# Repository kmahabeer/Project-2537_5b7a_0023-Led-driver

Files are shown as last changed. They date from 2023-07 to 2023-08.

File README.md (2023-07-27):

# LED Driver Circuit

Welcome to my photogrammetry project! Within this repository, you will find the KiCad PCB design, as well as the firmware for the LED driver circuit. The LED driver circuit is a crucial component in my photogrammetry project.

## Introduction

My photogrammetry project focuses on creating photorealistic digital clones using a low-budget image capture system with precise illumination facilitated by several LED driver circuits. Precise, multispectral lighting is important for accurate image capture. The images captured are used to recreate texture maps, including diffuse, specular, and roughness maps. Additionally, the images captured serve as valuable training data for creating deepfake models.

The LED driver circuit consists of constant current drivers powering five LEDs, including RGB LEDs, a PC Amber LED, and a neutral white LED. Each circuit incorporates a cost-effective 8-bit Microchip PIC16 microcontroller. Ethernet communication between a main computer through a Power over Ethernet (PoE) switch will be used<sup><a href="#item1">[1]</a></sup>. The microcontroller will most likely implement a lightweight TCP/IP stack where a main computer sends either UDP or TCP packets. While a UDP or TCP packet can be sent via simple commands from the main computer, a custom application will be developed to automate this process once several LED driver circuits are implemented.

Please note that the resources herein are intended solely for this specific project and should not be used elsewhere. My intent for creating the photogrammetry project is my own personal use, and is not intended to create digital clones of anyone besides myself.

## Components

Some important components included in the schematic:

- Microchip PIC16F18026
- Microchip PD70210
- Cree LED JE2835 3V N-Class LEDs
- Luxeon 2835E Neutral White LEDs

## Directory Structure

- `LED-driver-kicad/`: KiCad schematic files (.sch), KiCad PCB layout files (.kicad_pcb) for the main circuit.
- `firmware/`: Any firmware-related code for the microcontroller.
- `Documentation/`: Any relevant documentation or datasheets used in the design.

## References

<ol>
<li id="item1">
“IEEE Standard for Information technology-- Local and metropolitan area networks-- Specific requirements-- Part 3: CSMA/CD Access Method and Physical Layer Specifications Amendment 3: Data Terminal Equipment (DTE) Power via the Media Dependent Interface (MDI) Enhancements” <i>IEEE Standards Association</i>, 30 Oct. 2009, <a href="https://standards.ieee.org/ieee/802.3at/4553/" target="_blank" rel="noopener noreferrer">standards.ieee.org/ieee/802.3at/4553/</a>.
</li>
</ol>

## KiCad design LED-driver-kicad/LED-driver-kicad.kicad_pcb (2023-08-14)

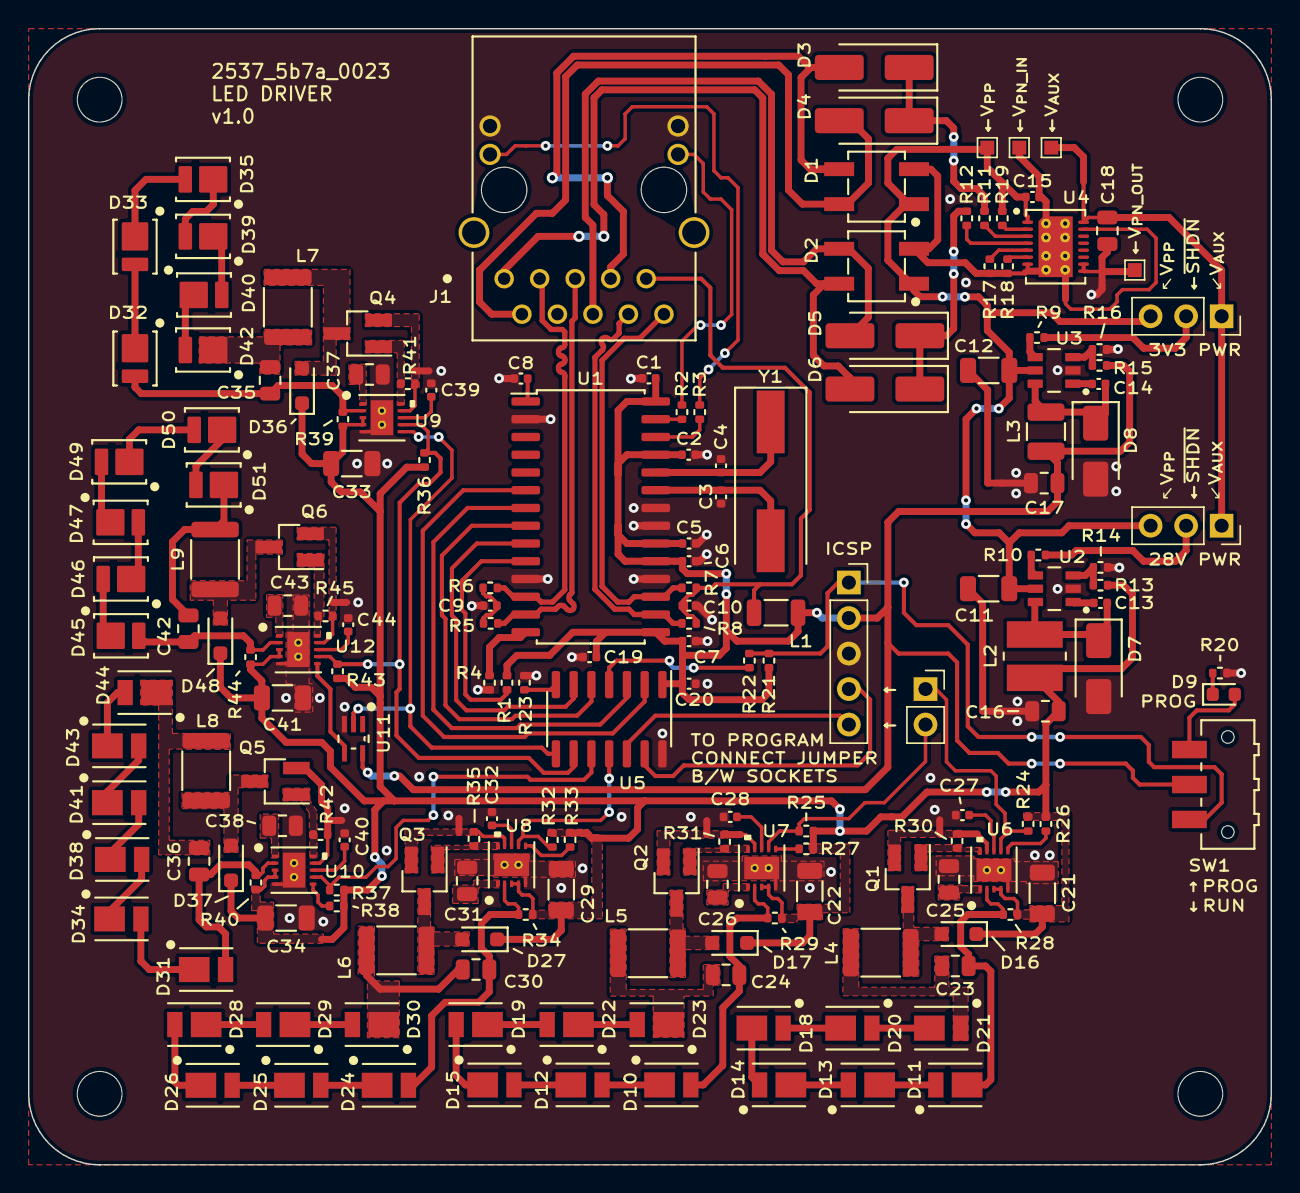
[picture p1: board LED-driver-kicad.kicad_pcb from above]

Board: 2 copper layers, 88.9 x 81.3 mm, 192 parts (0 on the bottom side), 140 nets.

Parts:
C1, C2, C5, C6, C7, C9, C10, C13, C14, C15, C20: 100n; C_0402_1005Metric
C3, C4: 18p; C_0402_1005Metric
C8: 10u; C_0402_1005Metric
C11, C12: 2u2; C_1206_3216Metric
C16, C18, C23, C24, C25, C26, C30, C31, C35, C36, C37, C38, C42, C43: 4u7; C_0805_2012Metric
C17: 22u; C_0805_2012Metric
C19: 10n; C_0402_1005Metric
C21, C22, C29, C33, C34, C41: 10u; C_1206_3216Metric
C27, C28, C32, C39, C40, C44: 470p; C_0402_1005Metric
D1, D2: D_Bridge_+A-A; D_TO-269AA_4-BESOP_Diodes_MB10S-13
D3, D4, D5, D6: D; D_SMA_Handsoldering
D7, D8: SMC SS110; D_SMA
D9: GREEN; LED_0603_1608Metric
D10, D12, D15, D19, D22, D23: GREEN; LED_Cree-JE2835_3V_NClass_Group-1
D11, D13, D14, D18, D20, D21: RED; LED_Cree-JE2835_3V_NClass_Group-2
D16, D17, D27, D36, D37, D48: SD103AWS; D_SOD-323_HandSoldering
D24, D25, D26, D28, D29, D30: BLUE; LED_Cree-JE2835_3V_NClass_Group-1
D31, D34, D38, D41, D43, D44: PCAmber; LED_Cree-JE2835_3V_NClass_Group-1
D32, D33, D35, D39, D40, D42, D45, D46, D47, D49, D50, D51: White; LED_Lumiled_Luxeon_2835E_3V
H1, H2, H3, H4: MountingHole; MountingHole_3.2mm_M3
J1: ARJM11C7-114-BA-EW2; Connector_RJ45_Abracon_ARJM11C7-114-BA-EW2
J2, J3: Conn_01x03_Socket; PinSocket_1x03_P2.54mm_Vertical
J4: Conn_01x05_Socket; PinSocket_1x05_P2.54mm_Vertical
J5: Conn_01x02_Socket; PinSocket_1x02_P2.54mm_Vertical
L1: Ferrite Bead; L_1206_3216Metric
L2: 100u; L_TDK_VLS4015CX-6R8M-H
L3: 22u; L_1210_3225Metric
L4, L5, L6, L7, L8, L9: 330u; L_1812_4532Metric
NT1, NT2, NT3, NT4, NT5, NT6, NT7, NT8, NT9, NT10: NetTie_2; NetTie-2_SMD_Pad0.5mm
Q1, Q2, Q3, Q4, Q5, Q6: Q_NMOS_GDS; SOT-23_Handsoldering
R1, R11, R12, R14, R16, R21, R30, R31, R35, R41, R42, R45: 10k; R_0402_1005Metric
R2, R3: 1k; R_0402_1005Metric
R4: 2k32; R_0402_1005Metric
R5, R6, R7, R8: 49R9; R_0402_1005Metric
R9, R10, R24, R25, R26, R27, R32, R33, R36, R37, R38, R43: 100k; R_0402_1005Metric
R13: 357k; R_0402_1005Metric
R15: 33k; R_0402_1005Metric
R17: 60k4; R_0402_1005Metric
R18: 30R9; R_0402_1005Metric
R19: 25k; R_0402_1005Metric
R20: 100; R_0402_1005Metric
R22, R23: 470; R_0402_1005Metric
R28, R29, R34, R39, R40, R44: 1.43; R_0402_1005Metric
SW1: SW_SPDT; SW_SPDT_CK-JS102011SAQN
TP1, TP2, TP3, TP4: TestPoint; TestPoint_Pad_1.0x1.0mm
U1: ENC28J60x-SO; SOIC-28W_7.5x17.9mm_P1.27mm
U2, U3: LV2862XLVDDCR; SOT-23-Thin-6_DDC0006A-MFG_Regulator_Voltage_TI_LV2862XLVDD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
U4: PD70210A; DFN-16_5X4_MCH-Interface_PoE_Microchip_PD70210A
U5: PIC16F18026-ISL; SOIC-14_3.9x8.7mm_P1.27mm
U6, U7, U8, U9, U10, U12: MIC3205YML-TR; MLF-10_ML_MCH-Driver_LED_Microchip_MIC3205YML-TR
U11: 74AHC1G14; SOT-353-DCK5-Logic_Diodes_74AHC1G14SE-7
Y1: 25MHz; Crystal_SMD_HC49-SD

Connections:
+3.3V: C1.1, C2.1, C5.1, C6.1, C7.1, C17.1, C19.1, C20.1, J4.2, L1.1, L3.2, R1.2, R15.1, R21.1, SW1.2 (B), U1.15 (VDDTX), U1.19 (VDDRX), U1.20 (VDDPLL), U1.25 (VDDOSC), U1.28 (VDD), U5.1 (VDD), U11.5 (VCC)
+28V: C16.1, C21.1, C22.1, C29.1, C33.1, C34.1, C41.1, D16.1 (K), D17.1 (K), D27.1 (K), D36.1 (K), D37.1 (K), D48.1 (K), L2.2, R13.1, R24.1, R25.1, R26.1, R27.1, R28.1, R29.1, R32.1, R33.1, R34.1, R36.1, R37.1, R38.1, R39.1, R40.1, R43.1, R44.1, U6.3 (VIN), U6.4 (VINS), U7.3 (VIN), U7.4 (VINS), U8.3 (VIN), U8.4 (VINS), U9.3 (VIN), U9.4 (VINS), U10.3 (VIN), U10.4 (VINS), U12.3 (VIN), U12.4 (VINS)
/Ethernet/RJ45_LED_L_ANODE: J1.13 (LED), R2.2
/Ethernet/RJ45_LED_R_ANODE: J1.11 (LED), R3.2
/Ethernet/RJ45_RD+: J1.5 (RD+), R5.1, U1.13 (TPIN+)
/Ethernet/RJ45_RD-: J1.3 (RD-), R6.1, U1.12 (TPIN-)
/Ethernet/RJ45_TCT: C10.1, J1.9 (TCT), L1.2, R7.2, R8.1
/Ethernet/RJ45_TD+: J1.10 (TD+), R7.1, U1.17 (TPOUT+)
/Ethernet/RJ45_TD-: J1.8 (TD-), R8.2, U1.16 (TPOUT-)
/LEDs - amber and white/PGND_AMBER: NT8.2, Q5.3 (S), R42.2, U10.9 (PGND)
/LEDs - amber and white/PGND_WHITE: NT9.1, Q4.3 (S), R41.2, U9.9 (PGND)
/LEDs - amber and white/PGND_WHITE_P: NT10.1, Q6.3 (S), R45.2, U12.9 (PGND)
/LEDs/PGND_BLUE: NT7.2, Q3.3 (S), R35.2, U8.9 (PGND)
/LEDs/PGND_GREEN: NT5.2, Q2.3 (S), R31.2, U7.9 (PGND)
/LEDs/PGND_RED: NT6.2, Q1.3 (S), R30.2, U6.9 (PGND)
/Microcontroller/MCU_ICSP_MCLR: J4.1, R21.2, R22.1, SW1.1 (A)
/Power/3V3_C_{IN}_GND: C12.2, NT2.1
/Power/3V3_~SHDN: J2.2, R9.2
/Power/28V_C_{IN}_GND: C11.2, NT1.1
/Power/28V_~SHDN: J3.2, R10.2
/Power/VAUX: C18.1, J2.1, J3.1, TP3.1, U4.16 (VAUX)
/Power/VPN_IN: C15.2, D1.3 (-), D2.3 (-), NT3.1, R17.2, R18.2, TP2.1, U4.7 (VPN_IN), U4.8 (VPN_IN), U4.17 (ePAD)
/Power/VPN_OUT: C18.2, NT4.2, TP4.1, U4.9 (VPN_OUT), U4.10 (VPN_OUT)
/Power/VPP: C11.1, C12.1, C15.1, D1.1 (+), D2.1 (+), J2.3, J3.3, R19.1, TP1.1, U2.5 (VIN), U3.5 (VIN), U4.1 (VPP)
/Power/WA_EN: NT3.2, U4.15 (WA_EN)
GND: C1.2, C2.2, C3.1, C4.1, C5.2, C6.2, C7.2, C8.2, C9.2, C10.2, C16.2, C17.2, C19.2, C20.2, C21.2, C22.2, C25.2, C26.2, C27.2, C28.2, C29.2, C31.2, C32.2, C33.2, C34.2, C37.2, C38.2, C39.2, C40.2, C41.2, C43.2, C44.2, D7.2 (A), D8.2 (A), J1.12 (LED), J1.14 (LED), J4.3, NT1.2, NT2.2, NT4.1, NT5.1, NT6.1, NT7.1, NT8.1, NT9.2, NT10.2, R4.1, R14.2, R16.2, R20.1, R23.1, U1.2 (VSS), U1.11 (VSSRX), U1.18 (VSSTX), U1.21 (VSSPLL), U1.22 (VSSOSC), U2.2 (GND), U3.2 (GND), U5.14 (VSS), U6.5 (AGND), U6.11 (ePAD), U7.5 (AGND), U7.11 (ePAD), U8.5 (AGND), U8.11 (ePAD), U9.5 (AGND), U9.11 (ePAD), U10.5 (AGND), U10.11 (ePAD), U11.3 (GND), U12.5 (AGND), U12.11 (ePAD)
MCU_CCP1: R36.2, R43.2, U5.9 (RC1), U9.7 (DIM), U12.7 (DIM)
MCU_CCP2: R37.2, U5.10 (RC0), U10.7 (DIM)
MCU_PWM3_OUT: R32.2, U5.11 (RA2), U8.7 (DIM)
MCU_PWM4_OUT: J5.2, R25.2, U7.7 (DIM)
MCU_PWM5_OUT: J5.1, R24.2, U6.7 (DIM)
MCU_SPI_ETH_CS: U1.9 (~CS), U5.6 (RC4)
MCU_SPI_SCK: U1.8 (SCK), U5.5 (RC5)
MCU_SPI_SDI/MOSI: U1.6 (SO), U5.2 (RA5)
MCU_SPI_SDO/MISO: U1.7 (SI), U5.3 (RA4)
MCU_WHITE_LED: U5.8 (RC2), U9.6 (EN), U11.2
unnamed: C9.1, R5.2, R6.2
unnamed: D3.1 (K), D4.1 (K), R11.2
unnamed: D5.1 (K), D6.1 (K), R12.1
unnamed: C13.2, D7.1 (K), L2.1, U2.6 (SW)
unnamed: C14.2, D8.1 (K), L3.1, U3.6 (SW)
unnamed: D9.2 (A), SW1.3 (C)
unnamed: D9.1 (K), R20.2
unnamed: C24.1, D10.2 (A), R29.2, U7.2 (CS)
unnamed: D10.1 (K), D12.2 (A)
unnamed: C23.1, D11.2 (A), R28.2, U6.2 (CS)
unnamed: D11.1 (K), D13.2 (A)
unnamed: D12.1 (K), D15.2 (A)
unnamed: D13.1 (K), D14.2 (A)
unnamed: D14.1 (K), D18.2 (A)
unnamed: D15.1 (K), D19.2 (A)
unnamed: D16.2 (A), L4.2, Q1.2 (D)
unnamed: D17.2 (A), L5.2, Q2.2 (D)
unnamed: D18.1 (K), D20.2 (A)
unnamed: D19.1 (K), D22.2 (A)
unnamed: D20.1 (K), D21.2 (A)
unnamed: C23.2, D21.1 (K), L4.1
unnamed: D22.1 (K), D23.2 (A)
unnamed: C24.2, D23.1 (K), L5.1
unnamed: C30.1, D24.2 (A), R34.2, U8.2 (CS)
unnamed: D24.1 (K), D25.2 (A)
unnamed: D25.1 (K), D26.2 (A)
unnamed: D26.1 (K), D28.2 (A)
unnamed: D27.2 (A), L6.2, Q3.2 (D)
unnamed: D28.1 (K), D29.2 (A)
unnamed: D29.1 (K), D30.2 (A)
unnamed: C30.2, D30.1 (K), L6.1
unnamed: C36.1, D31.2 (A), R40.2, U10.2 (CS)
unnamed: D31.1 (K), D34.2 (A)
unnamed: C35.1, D32.2 (A), R39.2, U9.2 (CS)
unnamed: D32.1 (K), D33.2 (A)
unnamed: D33.1 (K), D35.2 (A)
unnamed: D34.1 (K), D38.2 (A)
unnamed: D35.1 (K), D39.2 (A)
unnamed: D36.2 (A), L7.2, Q4.2 (D)
unnamed: D37.2 (A), L8.2, Q5.2 (D)
unnamed: D38.1 (K), D41.2 (A)
unnamed: D39.1 (K), D40.2 (A)
unnamed: D40.1 (K), D42.2 (A)
unnamed: D41.1 (K), D43.2 (A)
unnamed: C35.2, D42.1 (K), L7.1
unnamed: D43.1 (K), D44.2 (A)
unnamed: C36.2, D44.1 (K), L8.1
unnamed: C42.1, D45.2 (A), R44.2, U12.2 (CS)
unnamed: D45.1 (K), D46.2 (A)
unnamed: D46.1 (K), D47.2 (A)
unnamed: D47.1 (K), D49.2 (A)
unnamed: D48.2 (A), L9.2, Q6.2 (D)
unnamed: D49.1 (K), D50.2 (A)
unnamed: D50.1 (K), D51.2 (A)
unnamed: C42.2, D51.1 (K), L9.1
unnamed: J4.4, U5.13 (RA0/ICSPDAT)
unnamed: J4.5, U5.12 (RA1/ICSPCLK)
unnamed: Q1.1 (G), R30.1, U6.10 (DRV)
unnamed: Q2.1 (G), R31.1, U7.10 (DRV)
unnamed: Q3.1 (G), R35.1, U8.10 (DRV)
unnamed: Q4.1 (G), R41.1, U9.10 (DRV)
unnamed: Q5.1 (G), R42.1, U10.10 (DRV)
unnamed: Q6.1 (G), R45.1, U12.10 (DRV)
unnamed: R2.1, U1.27 (LEDA)
unnamed: R3.1, U1.26 (LEDB)
unnamed: C3.2, U1.23 (OSC1), Y1.2
unnamed: C4.2, U1.24 (OSC2), Y1.1
unnamed: R4.2, U1.14 (RBIAS)
unnamed: C8.1, U1.1 (VCAP)
unnamed: R1.1, U1.10 (~RESET)
unnamed: C13.1, U2.1 (CB)
unnamed: R13.2, R14.1, U2.3 (FB)
unnamed: R10.1, U2.4 (~SHDN)
unnamed: C14.1, U3.1 (CB)
unnamed: R15.2, R16.1, U3.3 (FB)
unnamed: R9.1, U3.4 (~SHDN)
unnamed: R18.1, U4.6 (RCLS)
unnamed: R19.2, U4.2 (RDET)
unnamed: R17.1, U4.5 (RREF)
unnamed: R11.1, U4.3 (SUPP_S1)
unnamed: R12.2, U4.4 (SUPP_S2)
unnamed: R23.2, U5.7 (RC3)
unnamed: R22.2, U5.4 (~MCLR/Vpp/RA3)
unnamed: C27.1, U6.8 (CTIMER)
unnamed: R26.2, U6.6 (EN)
unnamed: C25.1, U6.1 (VCC)
unnamed: C28.1, U7.8 (CTIMER)
unnamed: R27.2, U7.6 (EN)
unnamed: C26.1, U7.1 (VCC)
unnamed: C32.1, U8.8 (CTIMER)
unnamed: R33.2, U8.6 (EN)
unnamed: C31.1, U8.1 (VCC)
unnamed: C39.1, U9.8 (CTIMER)
unnamed: C37.1, U9.1 (VCC)
unnamed: C40.1, U10.8 (CTIMER)
unnamed: R38.2, U10.6 (EN)
unnamed: C38.1, U10.1 (VCC)
unnamed: C44.1, U12.8 (CTIMER)
unnamed: U11.4, U12.6 (EN)
unnamed: C43.1, U12.1 (VCC)
RJ45_VC1+: D1.4, D3.2 (A), J1.7 (VC1+)
RJ45_VC1-: D1.2, D4.2 (A), J1.2 (VC1-)
RJ45_VC2+: D2.4, D5.2 (A), J1.6 (VC2+)
RJ45_VC2-: D2.2, D6.2 (A), J1.1 (VC2-)

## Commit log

2023-07-19 create kicad project
    [LED-driver-kicad.kicad_pcb, LED-driver-kicad.kicad_sch]
2023-07-22 add symbols and footprints
2023-07-22 update KiCad schematic
    [LED-driver-kicad.kicad_sch]
2023-07-27 chore: add kicad library as submodule
2023-07-27 chore: add RJ45 connector and PoE controller symbols to kicad project library
2023-07-27 add separate hierarchical sheets for ethernet and main microcontroller
    [Ethernet.kicad_sch, LED-driver-kicad.kicad_sch, Microcontroller.kicad_sch]
2023-07-27 chore: update kicad library submodule
2023-07-27 chore: update ethernet.kicad_sch
    [Ethernet.kicad_sch]
2023-07-27 chore: update Microcontroller.kicad_sch
    [Microcontroller.kicad_sch]
2023-07-27 update symbol library locations
    [LED-driver-kicad.kicad_sch]
2023-07-27 update ENC28J60x-SO circuit
    [Ethernet.kicad_sch]
2023-07-27 update main schematic sheet and microcontroller
    [LED-driver-kicad.kicad_sch, Microcontroller.kicad_sch]
2023-07-27 remove unused libraries
    [LED-driver-kicad.kicad_sch]
2023-07-30 update schematic for RJ45 connector and Ethernet controller
    [Ethernet.kicad_sch]
2023-07-30 update schematic for main microcontroller
    [Microcontroller.kicad_sch]
2023-07-30 add schematics for power controller and LEDs
    [LEDs.kicad_sch, Power.kicad_sch]
2023-07-30 update main schematic sheet
    [LED-driver-kicad.kicad_sch]
2023-08-01 update Power schematic
    [Power.kicad_sch]
2023-08-01 remove surge protection and wall adapter circuit
    [Power.kicad_sch]
2023-08-01 update RGB LED driver circuits
    [LEDs.kicad_sch, Power.kicad_sch]
2023-08-02 update *MCLR switch for microcontroller
    [Microcontroller.kicad_sch]
2023-08-02 remove EEPROM MAC address IC
    [Microcontroller.kicad_sch]
2023-08-02 remove VDDA decoupling
    [Power.kicad_sch]
2023-08-02 add schematic sheet for white and PC amber LED
    [LED-driver-kicad.kicad_sch, LEDs-amber_white.kicad_sch]
2023-08-02 update RGB LEDs
    [LEDs.kicad_sch]
2023-08-02 connect unused IO to pull down resistor
    [Microcontroller.kicad_sch]
2023-08-02 replace MOSFETs with generic n-channel MSOFETs
    [LEDs-amber_white.kicad_sch, LEDs.kicad_sch]
2023-08-02 replace push-pull MOSFET circuit with LED driver with inverter gate enable
    [LEDs-amber_white.kicad_sch]
2023-08-02 update comments and title blocks
    [Ethernet.kicad_sch, LED-driver-kicad.kicad_sch, LEDs-amber_white.kicad_sch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]
2023-08-02 update 3V3 power supply circuit
    [Power.kicad_sch]
2023-08-02 update 28V power supply circuit
    [Power.kicad_sch]
2023-08-02 update component designators
    [Ethernet.kicad_sch, LEDs-amber_white.kicad_sch, LEDs.kicad_sch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]
2023-08-03 resolve Electrical Rules Checker (ERC) errors and warnings
    [Ethernet.kicad_sch, LEDs.kicad_sch, Microcontroller.kicad_sch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]
2023-08-03 update footprints
2023-08-03 update footprint assignments
    [Ethernet.kicad_sch, LEDs-amber_white.kicad_sch, LEDs.kicad_sch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]
2023-08-05 initial PCB layout
    [LED-driver-kicad.kicad_pcb, LEDs-amber_white.kicad_sch, LEDs.kicad_sch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]
2023-08-08 update initial components layout
    [Ethernet.kicad_sch, LED-driver-kicad.kicad_pcb, LED-driver-kicad.kicad_sch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]
2023-08-12 add test points, net ties to schematics
    [Ethernet.kicad_sch, LEDs-amber_white.kicad_sch, LEDs.kicad_sch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]
2023-08-12 update PCB traces and planes
    [LED-driver-kicad.kicad_pcb]
2023-08-14 update silkscreen layer for component designators
    [LED-driver-kicad.kicad_pcb]
2023-08-14 update PCB version number
    [LED-driver-kicad.kicad_pcb]
